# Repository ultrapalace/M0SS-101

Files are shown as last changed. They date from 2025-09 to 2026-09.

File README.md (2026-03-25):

# M0SS-101

Join our Discord server: [https://discord.gg/w7DQAhY46v](https://discord.gg/w7DQAhY46v)  

For the build guide, see [build-guide.md](build-guide.md)  
For the user manual, see [manual.md](manual.md)  
For the guide to update your firmware, see [firmware-update-guide.md](firmware-update-guide.md)

Here is a printable version of the booklet: [booklet-v1.pdf](booklet-v1.pdf)

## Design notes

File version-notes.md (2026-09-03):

**V 1.0** - October 1st, 2025
- Initial release.
---
**V 1.1** - March 25th, 2026
- Bug fix: Program Change above 17 crashed the device.
- Bug fix: USB MIDI did not respect Program Change or Channel Pressure commands.
- Bug fix: Undocumented default CC mappings existed. I removed them.
- Bug fix: Only the first MIDI USB cable was read (MIDI devices with multiple cables not respected).
- Feature: Button combo to clear all learned CC mappings (**ALT + LFO.ENV + OSC-2 WAV + click knob**).
---
**V 1.2** - April 18th, 2026
- Bug fix: Note-off should purge all matching notes in the stack.
---
**V 1.2_dualenv** - April 18th, 2026
- Feature: Dual Envelopes, press **ALT + A** to toggle between ENV I and ENV II.
    ENV I is green as usual, ENV II is lightblue.
    Anything you can do with ENV I you can also do with ENV II
- NOTE: This firmware removes ADSR curves, you are stuck with linear.
---
**V 1.3** - Aug 21st, 2026
- Feature: MIDI Channel is global. It now auto-saves, and persists resets.
- Feature: ENV and LFO are additive on the VCA. This also means that 
---
**V 1.3_dualenv** - Aug 21st, 2026
- Feature: MIDI Channel is global. It now auto-saves, and persists resets.
- Feature: ENV and LFO are additive on the VCA. This also means that 
- NOTE: This firmware removes ADSR curves, you are stuck with linear.
- NOTE: ENV-II is in ENV-INVERSION mode in your patch, this will now pin the VCA open! This is a consequence of the additive behaviour. You may need to update your patches to turn ENV-INVERSION mode off for ENV-II.
---
**V 1.4** - Sept 3rd, 2026
- Feature: Parse complex USB descriptors like Minichord.
- Bug Fix: Presets from Dual-Env firmware should survive migrating device to/from normal firmware.
---
**V 1.4_dualenv** - Sept 3rd, 2026
- Feature: Parse complex USB descriptors like Minichord.
- Bug Fix: Presets from Dual-Env firmware should survive migrating device to/from normal firmware.
---

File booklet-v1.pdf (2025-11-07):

M0SS-101 is a monophonic virtual analog synth, programmed in the Faust DSP language, on the BL616 microcontroller, which includes:

2 oscillators (OSC), with stackable square and sawtooth waveforms, each with octave (OCT) and pulse width (PW) control. Oscillator 2 can be detuned (DTN).
1 filter (VCF), with high-pass, low-pass or bandpass response, resonance control, and optional key-tracking (K-T).
1 low frequency oscillator (LFO), with square (SQR), triangle (TRI), or random (RND) waveforms, and a frequency (FRQ) range of 0.01hz to 10khz.
1 amplifier (VCA).
1 envelope generator (ENV), with attack, decay, sustain and release controls (ADSR), with timings from 0.1ms to 20s, adjustable curves, and a gain inversion mode.
1 noise generator (NSE) with pink (PN) or white (WN) noise algorithms.
1 XOR module, applied to the square waves of the 2 oscillators.
1 mixer (MXR) with inputs from each oscillator, the noise generator, and the XOR module.

1 delay module, with time (D-TM), feedback (D-FB), and mix (D-MX) controls.
1 glide module with adjustable speed.
1 pitch-bend module with adjustable upward and downward range.
9 modulation paths with individual gain, connecting the LFO and ENV to the VCF cutoff, PW, OSC-1 pitch, and VCA, or to trigger the ENV from the LFO square wave. 1 flash memory unit to store up to 17 presets, and to remap MIDI channels per preset.
2 MIDI inputs (USB-A Host and 1/8" Type-A input), with OMNI / assignable channel.
1 MIDI thru 1/8" Type-A output.
1 1/4" mono audio output, line level, 100kOhm impedance.
1 9V dc power input, center negative.
1 knob to adjust parameters, which can be depressed (clicked) to trigger the ENV.

GLOSSARY
WAV | = waveform
SQR | = square waveform
SAW | = sawtooth waveform
PW | = pulse width
OCT | = octave
MXR | = mixer
NSE | = noise generator
LFO | = low frequency oscillator
WN.PN | = white noise or pink noise
TRI | = triangle waveform
RND | = random waveform
FRQ | = frequency
LO-HI | = low or high range
CTF | = cutoff
RES | = resonance
HP | = high pass
LP | = low pass
BP | = band pass
K-T | = key tracking
A | = attack
D | = decay
S | = sustain
R | = release
D-TM | = delay time
D-FB | = delay feedback
D-MX | = delay mix

M0SS-101 USER MANUAL - V.1 - ULTRAPALACE 2025

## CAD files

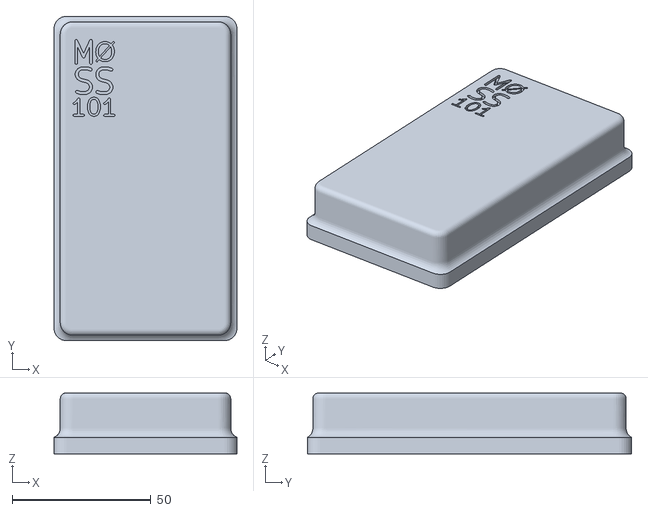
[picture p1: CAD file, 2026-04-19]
DustCover/moss-101-case_v35.stl
66.0 x 117.0 x 22.0

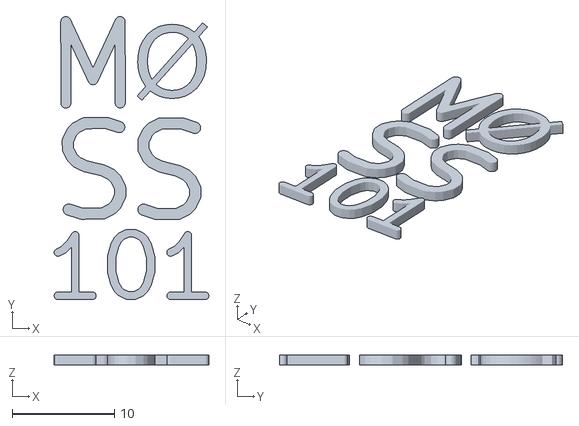
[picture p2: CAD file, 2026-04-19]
DustCover/moss-101-text_v35.stl
15.2 x 27.7 x 1.00

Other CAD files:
DustCover/moss-101_v35.step
DustCover/moss-101-no-text_v35.stl
DustCover/moss-101_v35.3mf

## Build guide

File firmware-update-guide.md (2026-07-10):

# M0SS-101 Firmware Update Guide

> NOTE: Updating the Firmware will usually result in the loss of your Presets

## STEP 1: Download the firmware image to your computer.
- The firmware Images are located in the `firmware` directory of this repository.
- You can read the [version notes](https://github.com/ultrapalace/M0SS-101/blob/main/version-notes.md) to pick the one you want to use.
- Download it to a good spot on your computer.
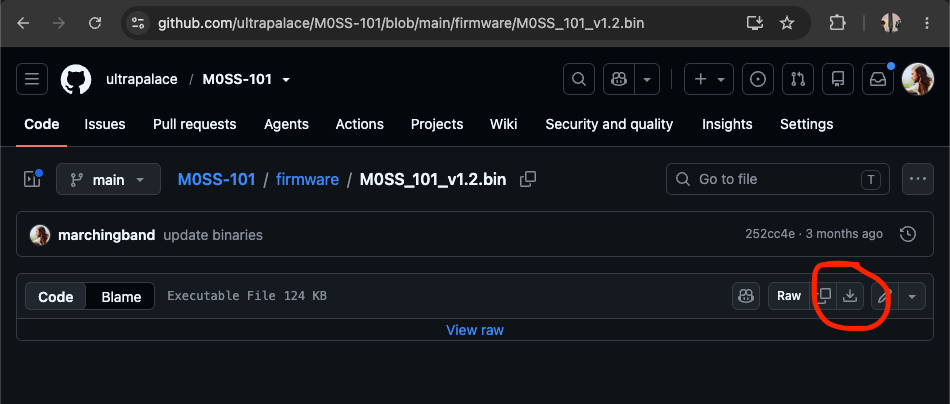
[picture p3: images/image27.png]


## STEP 2: Connect the M0SS-101
- Remove all the jacks from the M0SS-101
- Remove the 4 screws
- Remove the nut on the 1/4" Audio Jack
- Gently remove the guts of the M0SS-101
- Look for a small USB-B jack near the USB-A Host jack
- Using a USB-B cable, connect your computer to this small USB-B jack.
- Connect your 9v PSU to provide power to the M0SS-101
- It should look like this:
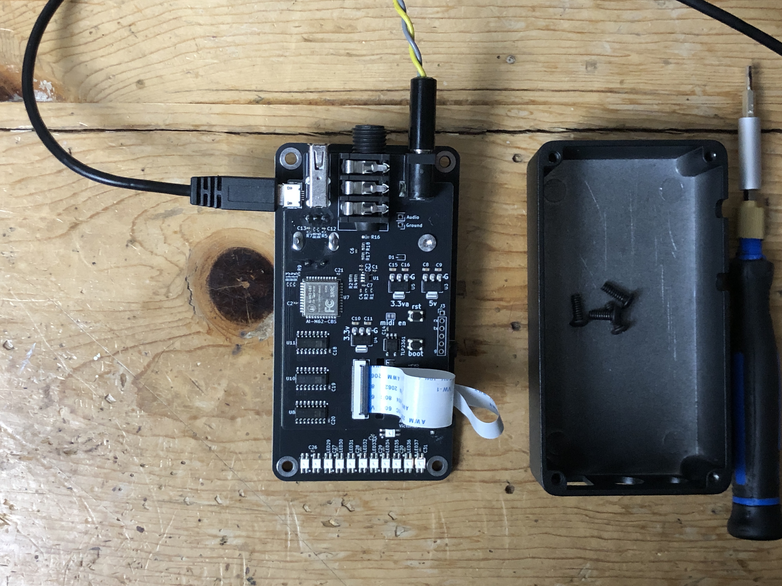
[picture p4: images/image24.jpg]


## STEP 3: Place M0SS-101 in bootloader mode
- Above the FFC cables, you will see 2 buttons labeled `BOOT` and `RST`.
- Hold the `BOOT` button down, and then click (press and release) the `RST` button. Finally release the `BOOT` button.

## STEP 4: Setup the M0SS Web Flasher utility
- Using Google Chrome (or another browser that supports WebUSB), open [https://philmillman.github.io/M0SSFlash/](https://philmillman.github.io/M0SSFlash/)
- click `Drop a .bin file here or click to browse` and select the image file you downloaded to your computer
- click `Connect Serial`, and select `Bouffalo CDC Demo` (this is the M0SS-101)

## STEP 5: Flash the firmware image
- click `Flash Firmware`
- watch the logs appear, the last log should say `Flash complete`
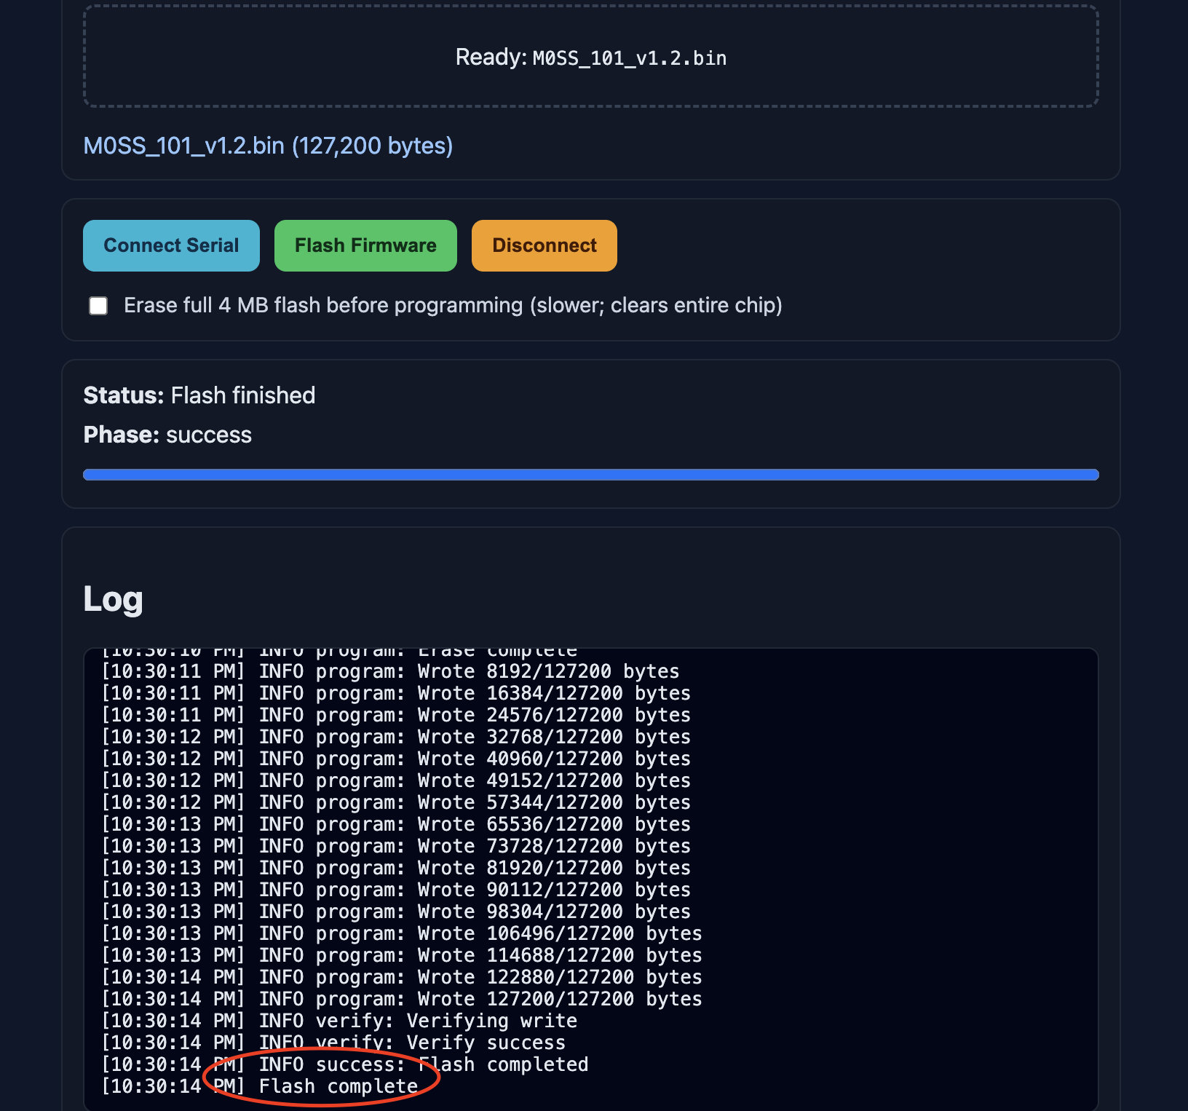
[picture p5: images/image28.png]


## STEP 6: Reset the M0SS-101
- disconnect power
- disconnect USB
- reassemble M0SS-101

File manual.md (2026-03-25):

# M0SS-101 Manual

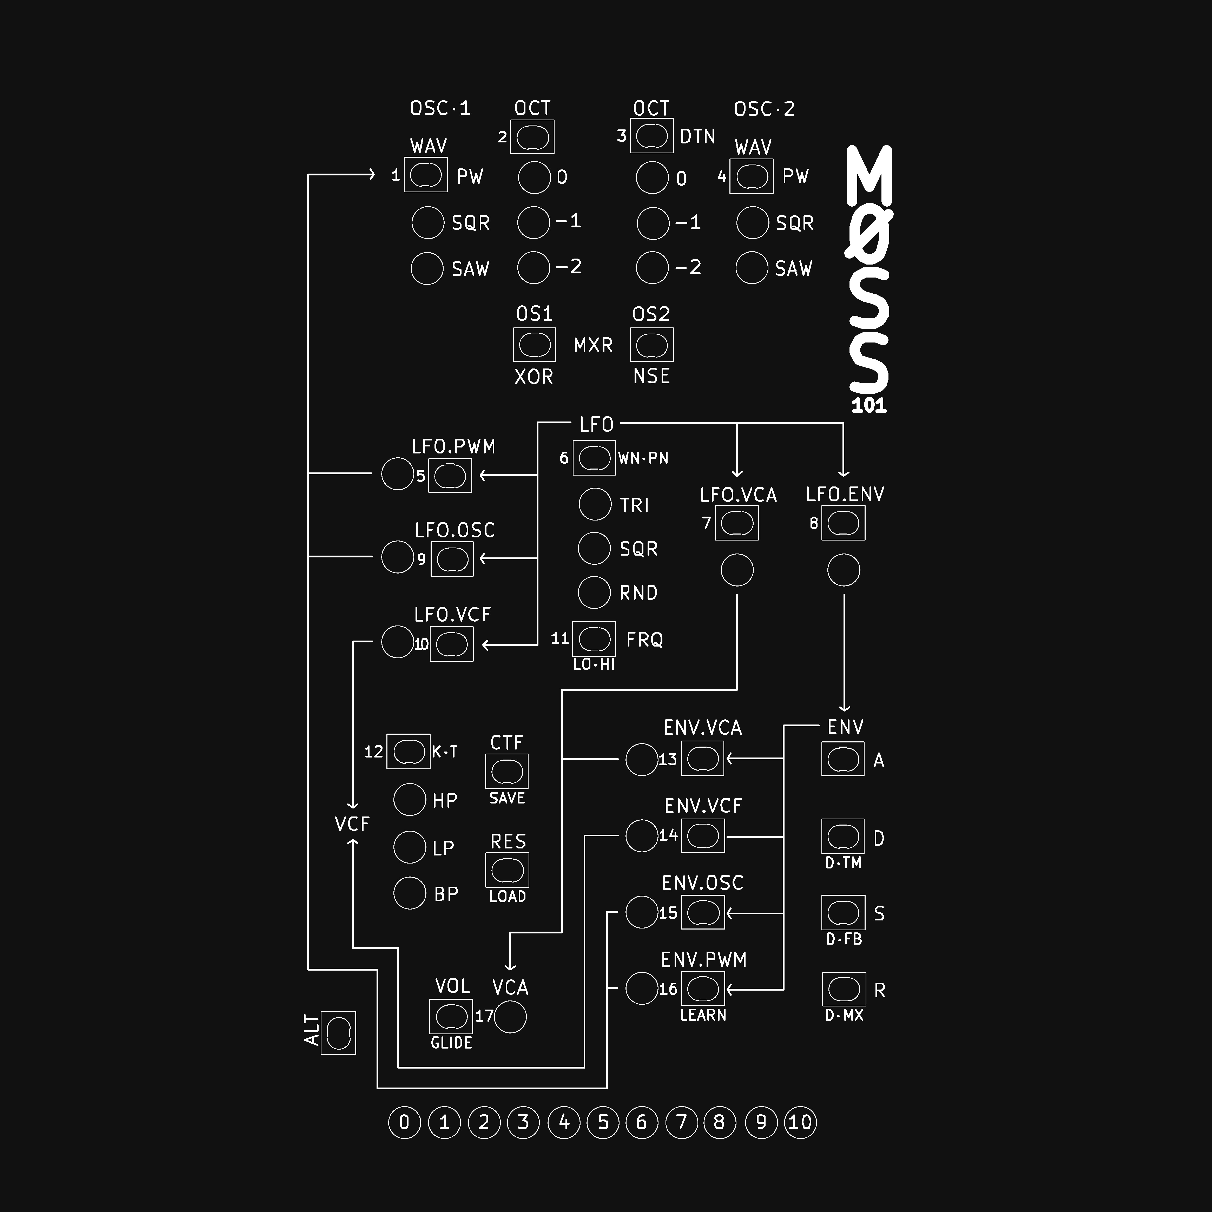
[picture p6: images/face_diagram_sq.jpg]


M0SS-101 is a monophonic virtual analog synth, programmed in the Faust DSP language, on the BL616 microcontroller, which includes:

- 2 oscillators (OSC), with stackable square and sawtooth waveforms, each with octave (OCT) and pulse width (PW) control. Oscillator 2 can be detuned (DTN).
- 1 filter (VCF), with high-pass, low-pass or bandpass response, resonance control, and optional key-tracking (K-T).
- 1 low frequency oscillator (LFO), with square (SQR), triangle (TRI), or random (RND) waveforms, and a frequency (FRQ) range of 0.01hz to 10khz.
- 1 amplifier (VCA).
- 1 envelope generator (ENV), with attack, decay, sustain and release controls (ADSR), with timings from 0.1ms to 20s, adjustable curves, and a gain inversion mode.
- 1 noise generator (NSE) with pink (PN) or white (WN) noise algorithms.
- 1 XOR module, applied to the square waves of the 2 oscillators.
- 1 mixer (MXR) with inputs from each oscillator, the noise generator, and the XOR module.
- 1 delay module, with time (D-TM), feedback (D-FB), and mix (D-MX) controls.
- 1 glide module with adjustable speed.
- 1 pitch-bend module with adjustable upward and downward range.
- 9 modulation paths with individual gain, connecting the LFO and ENV to the VCF cutoff, PW, OSC-1 pitch, and VCA, or to trigger the ENV from the LFO square wave.
- 1 flash memory unit to store up to 17 presets, and to remap MIDI channels per preset.
- 2 MIDI inputs (USB-A Host and 1/8" Type-A input), with OMNI / assignable channel.
- 1 MIDI thru 1/8" Type-A output.
- 1 1/4" mono audio output, line level, 100kOhm impedance.
- 1 9V dc power input, center negative.
- 1 knob to adjust parameters, which can be depressed (clicked) to trigger the ENV.

The primary function of each control is stamped above the control.  
The secondary function is stamped to the right, or beneath the control, hold ATL to access the secondary function.

If you activate a control, the row of bulbs near the bottom will often display its value in one of two ways:

**FADER:** this shows a value from 0 to 100, each bulb represents 10, and its faded value represents the 1's.  
**SWITCH:** the left 5 bulbs glow for on, the right 5 for off.

Most toggling and switching controls have a corresponding bulb which will glow yellow to indicate its state.  
For most signals, a corresponding bulb will glow green, pulsing with its signal level.

When the LFO is set to its high range (LO-HI), this signal will instead show as red~yellow, and the color temperature indicates its frequency.

Sometimes a control will have a specific numeric value (ex. MIDI channel).  
In this case a bulb will light near a control which has a small number stamped to its left.  
There are bulbs and controls for numbers 1 ~ 17.

---

## ENV GAIN INVERSION

When this control is active (it is active by default) attenuating the ENV.VCA signal will result in a higher initial gain for this signal.  
When this control is deactivated, the ENV.VCA signal operates more intuitively, where attenuating the signal results in a lower maximum gain.

---

## SAVE

1. Activate save mode (ATL + CTF) - free slots glow green, occupied slots glow orange.  
2. Press any slot to save (this can overwrite a slot).

---

## LOAD

1. Activate load mode (ALT + RES) - current slot glows green, loadable slots glow yellow.  
2. Press any loadable slot to load it (you will lose your current settings, if not saved)

**NOTE**  
Preset 17 comes pre-saved with some default settings. This is the preset that will always load at startup. You can customize your defaults by saving to this slot.

---

## Unmarked Controls

- **Hold (ALT + LFO.VCF)** = pitch-bend down semitones (1 ~ 12)
- **Hold (ALT + LFO.OSC)** = pitch-bend up semitones (1 ~ 12)
- **Hold (ALT + LFO.PWM)** = MIDI channel (1 ~ 17, 17 = OMNI)
- **Hold (ALT + A)** = ENV curves (1 ~ 9) (1 = very logarithmic, 5 = linear, 9 = very exponential)
- **Hold ALT + click knob + turn knob** = transpose pitch (semitones)
- **Hold ALT + turn knob** = fine-tune pitch (cents)
- **ALT + ENV.VCA** = ENV inversion mode (de)activate
- **ALT + LFO.ENV + click knob** = Panic/Reset
- **ALT + LFO.ENV + OSC-1 WAV + OSC-2 WAV + click knob** = Full Factory Reset
- **ALT + LFO.ENV + OSC-2 WAV + click knob** = Remove learned CCs for preset (added in v1.1)

---

## MIDI LEARN

1. Activate MIDI learn mode (ALT + ENV.PWM) - bulbs all glow orange.  
2. Select any control parameter - bulbs all glow yellow.  
3. Send any MIDI CC - bulbs all glow green (optionally repeat steps 2 and 3).  
4. Press ALT to exit.

This CC is now mapped to this control parameter. Save the preset to conserve this mapping.

To map aftertouch, hold a note on the keyboard, perform steps 1 and 2, then modulate the aftertouch.  
To map velocity, perform steps 1 and 2, and then press a key on the keyboard.

**NOTE**  
MIDI mappings are saved per preset.

---

## GLOSSARY

| Term | Meaning |
|---|---|
| WAV | waveform |
| SQR | square waveform |
| SAW | sawtooth waveform |
| PW | pulse width |
| OCT | octave |
| MXR | mixer |
| NSE | noise generator |
| LFO | low frequency oscillator |
| WN.PN | white noise or pink noise |
| TRI | triangle waveform |
| RND | random waveform |
| FRQ | frequency |
| LO-HI | low or high range |
| CTF | cutoff |
| RES | resonance |
| HP | high pass |
| LP | low pass |
| BP | band pass |
| K-T | key tracking |
| A | attack |
| D | decay |
| S | sustain |
| R | release |
| D-TM | delay time |
| D-FB | delay feedback |
| D-MX | delay mix |

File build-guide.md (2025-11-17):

# M0SS-101 BUILD GUIDE
( last updated November 17, 2025 )

## Here are the contents of the kit

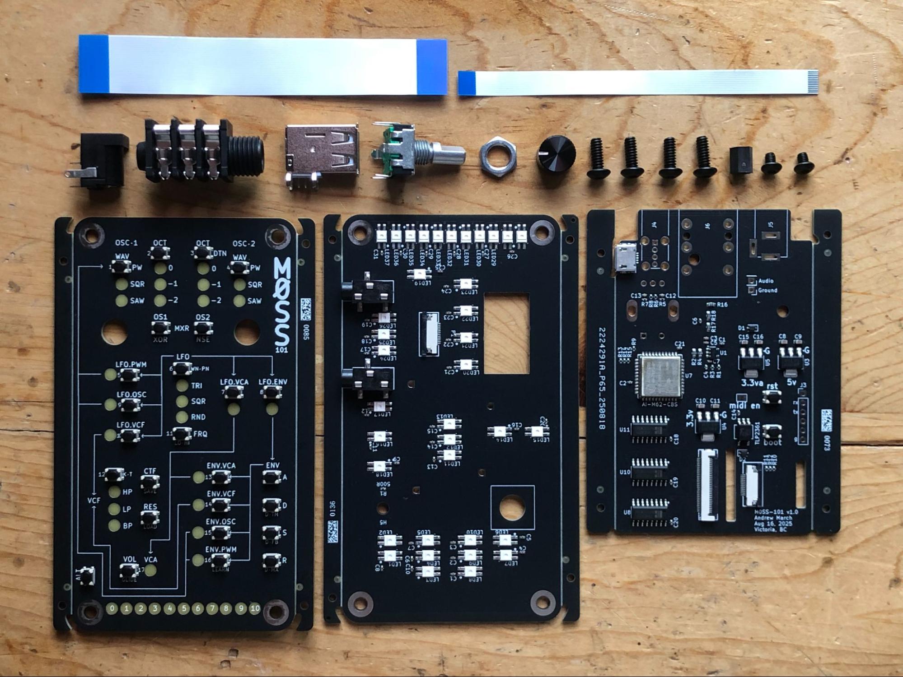
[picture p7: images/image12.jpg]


| Quantity | Item |
|---|---|
| 3 | PCBs (front panel, LED board, main board) |
| 1 | 30p Flat Flex cable |
| 1 | 12p Flat Flex cable |
| 1 | Encoder + nut |
| 1 | Encoder Knob |
| 1 | DC jack |
| 1 | 1/4" Audio jack + washer + nut |
| 1 | USB A jack |
| 1 | 7mm Standoff |
| 2 | M2 x 4mm screw, T8 |
| 5 | 6-32 x 3/8" screw, Hex |
| 4 | Silicon Feet (not pictured) |
| 1 | Aluminum enclosure (not pictured) |

<br/>

## You will need
- Pliers
- Soldering Iron
- Solder
- A T8 torx bit and driver
- A 2mm Allen Wrench or 2mm hex bit and driver
- Super Glue (optional)

<br/>

## STEP 1: Add solder to the 1/8" jacks
- These parts were sometimes not soldered well at the manufacturer. Add solder to the 6 tabs (3 tabs on each 1/8" jack) to reinforce them. During this process be VERY cautious to not melt the plastic parts of the jack, nor any of the surrounding parts, like LEDs. You can optionally add one drop of super glue to add strength, place it at the base of the part near the outside edge of the board, but be very careful not to add more then 1 drop, or you risk glueing the part shut!

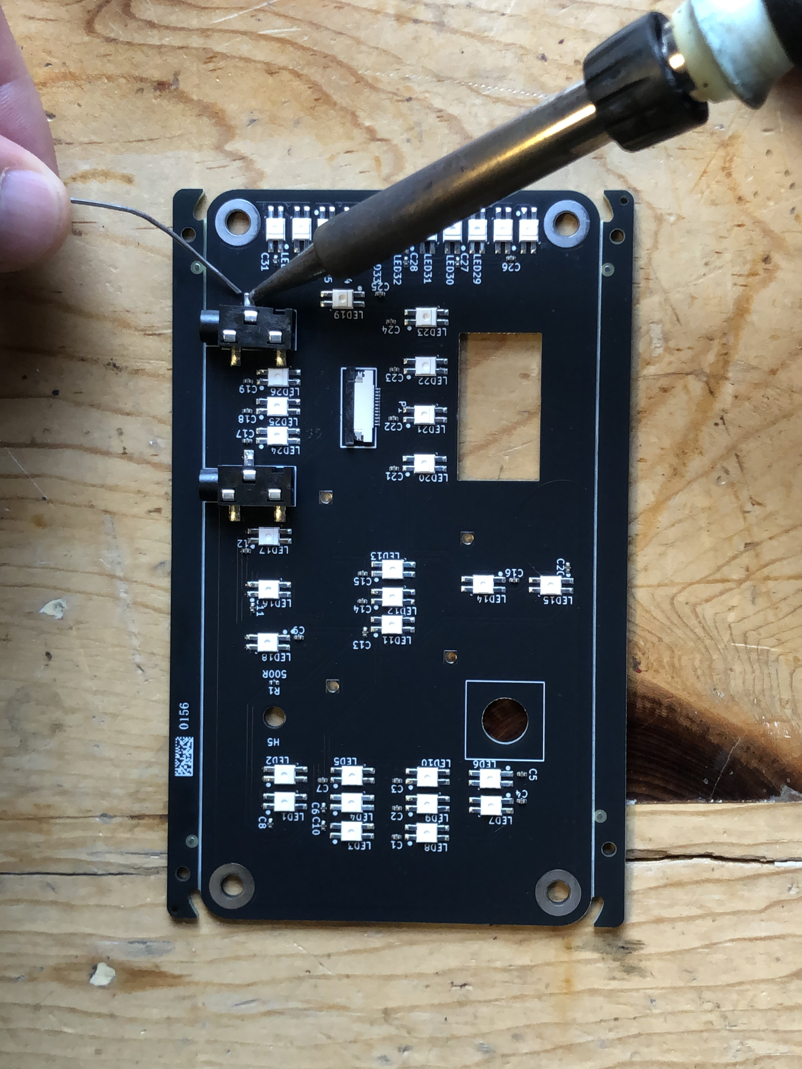
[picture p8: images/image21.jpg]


<br/>

## STEP 2: Remove the edge rails from all PCBs

- Using pliers, carefully snap off the edge rails. There are rails on the left and right sides of each PCB, 6 edges in total to be removed.

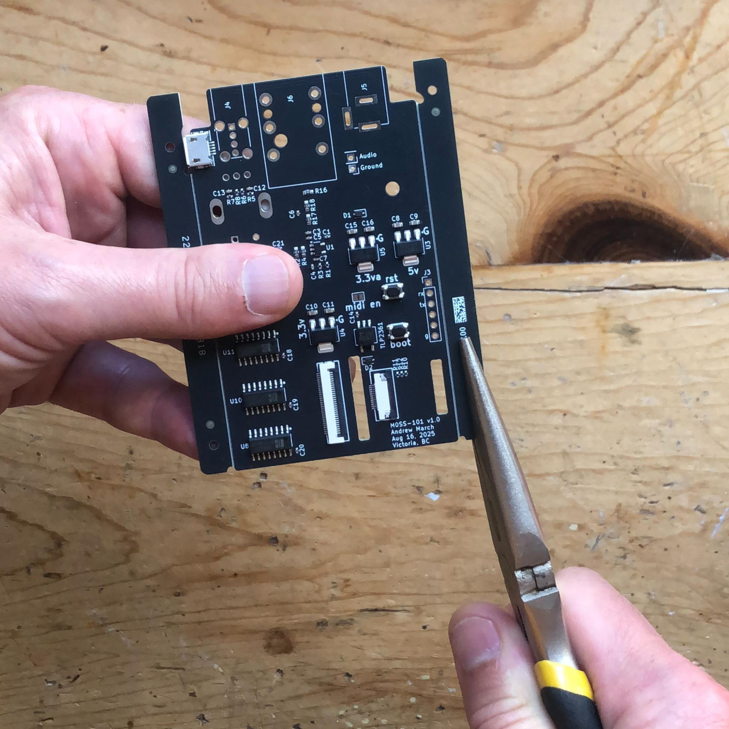
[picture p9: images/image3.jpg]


<br/>

## STEP 3: Place and solder the encoder

- Confirm you are placing the encoder on the correct side, by checking for the white outlined shape of the part, drawn on the PCB. The encoder goes on the back side.  
- Slightly bend the lugs of the encoder inward, using pliers, or by gently pressing them into the table.  
- Carefully place the encoder. If the lugs will not go in, bend them inward a little more.  
- Solder one pin of the encoder, and check that it is seated correctly.  
- Proceed to solder all the pins, and then the lugs.

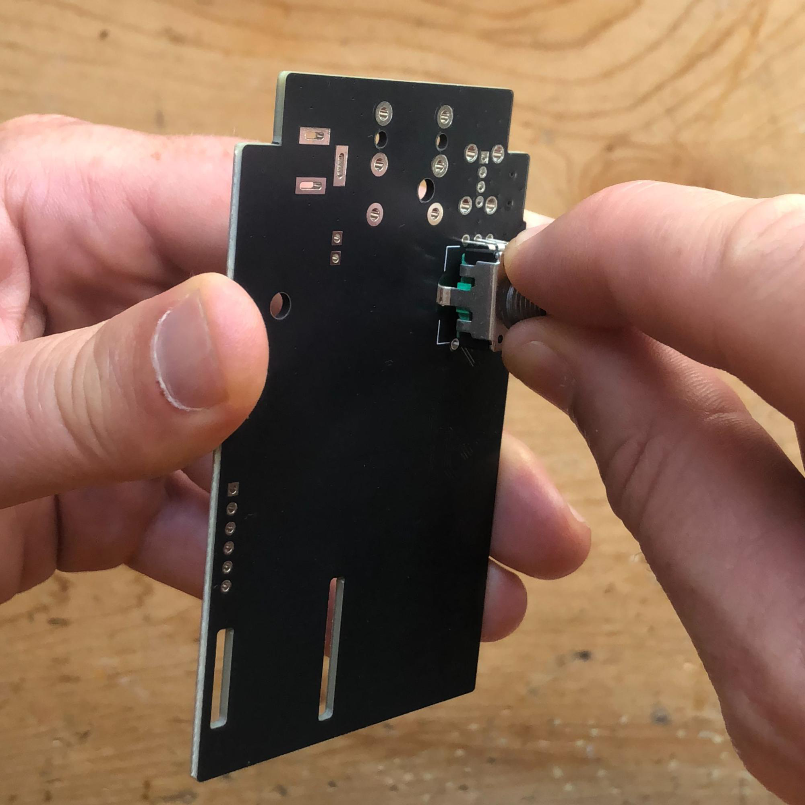
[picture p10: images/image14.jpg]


<br/>

## STEP 4: Place and solder the DC jack, audio jack and USB jack

- These parts are placed on the top side of the main PCB, look for the footprint outlines to confirm, these are installed on the opposite side as the encoder.  
- Start with the DC jack, and solder one pin, then adjust the position of the jack to be as square and straight as possible, using the white footprint outline, before soldering the remaining 2 pins.  
- Now place, and then solder, the USB jack and the audio jack.

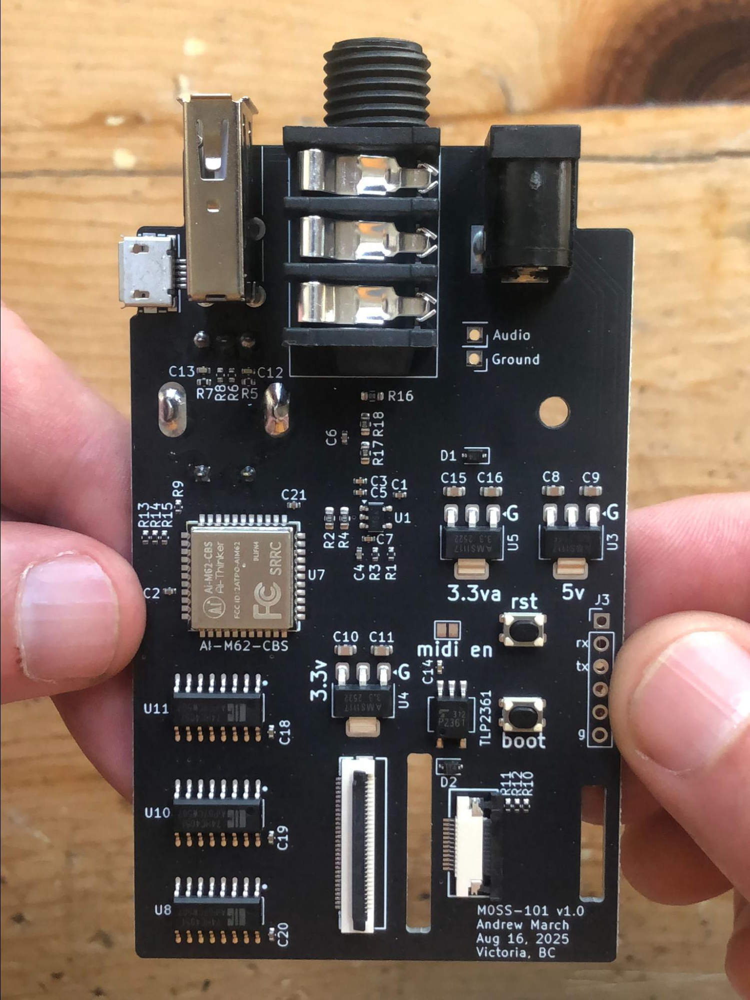
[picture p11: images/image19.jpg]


<br/>

## STEP 5: Install the standoff

- The standoff goes on the same side as the encoder, the back side of the main PCB.  
- Use a M2 x 4mm screw, and be careful to not over tighten it. ⅛ of a turn past hand-tight is great.

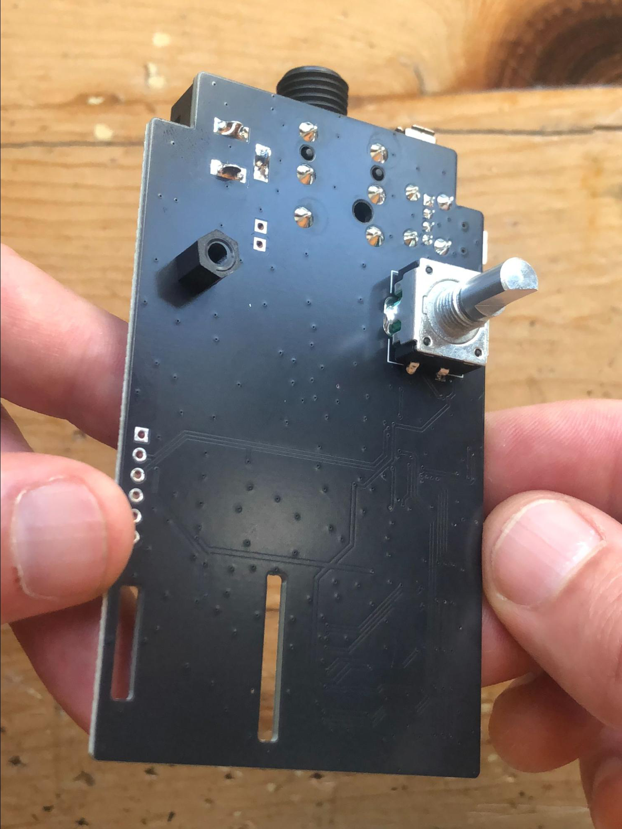
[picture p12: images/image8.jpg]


<br/>

## STEP 6: Install the Flat Flex Cables (FFCs)

- Install the large FFC onto the back side of the front panel board. The large FFC connector is a flip-lock type. Using a small tool or a fingernail, lift the black lock up and back to fully open the connector.   
- Insert the large FFC with the blue stripe up. Ensure it is fully seated and square, then close the lock.

<br/>

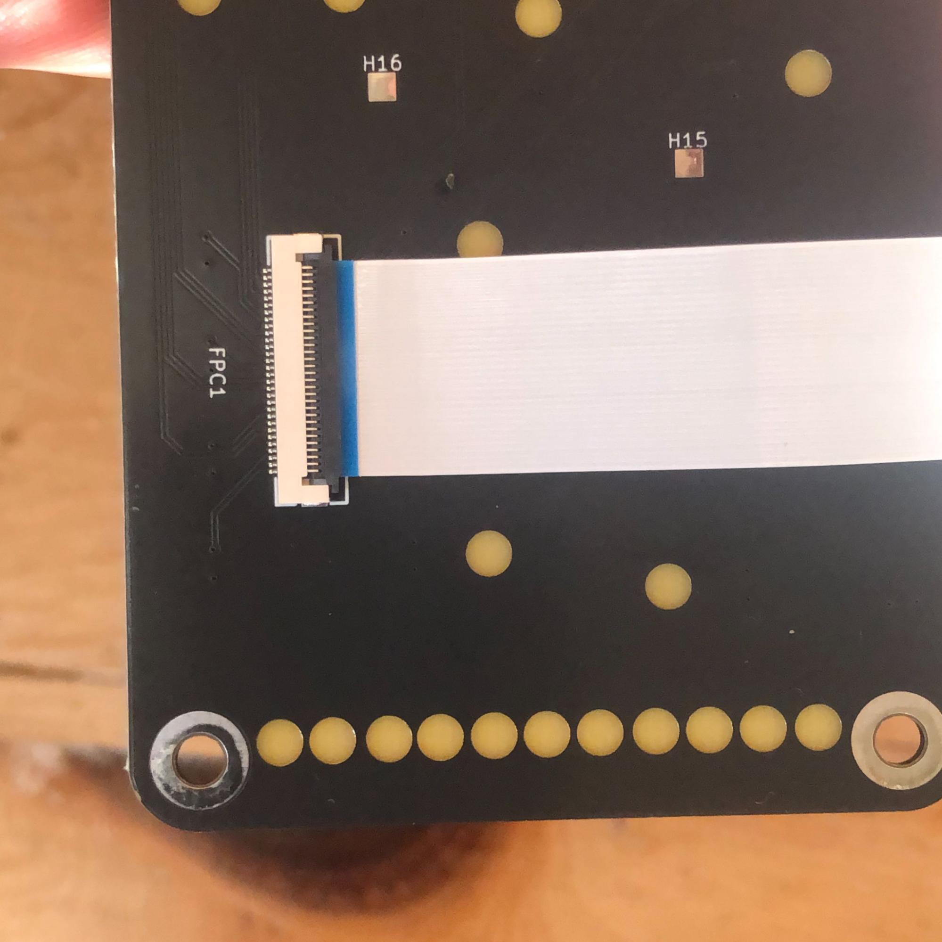
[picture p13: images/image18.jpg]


- Install the small FFC onto the LED board. The small FFC connector is a drawer-type. Using a small tool or a fingernail, gently pull laterally on the black lock to open it like a drawer.  
- Insert the small FFC with the blue stripe up, sliding it under the lock, and gently wiggle it into place. This may take some patience, and it is ok to try the other end, if you are struggling.  
- Lock the connector by pressing the drawer back into the closed position.

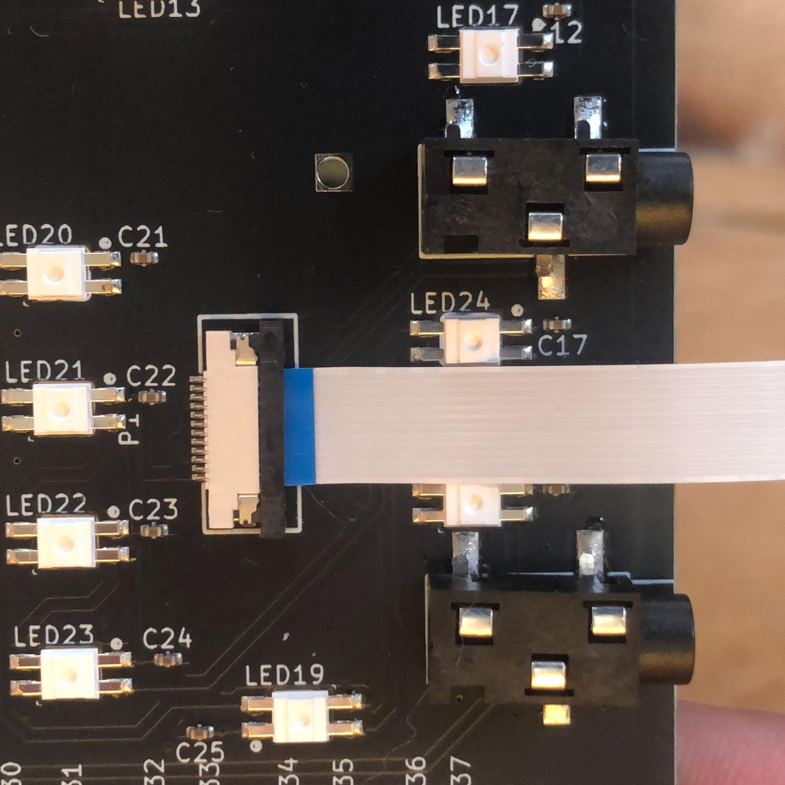
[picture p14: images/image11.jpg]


<br/>

## STEP 7: Assemble the stack-up.

- Thread the large FFC through the large cutout in the LED board, and bring the 2 boards together back-to-back.

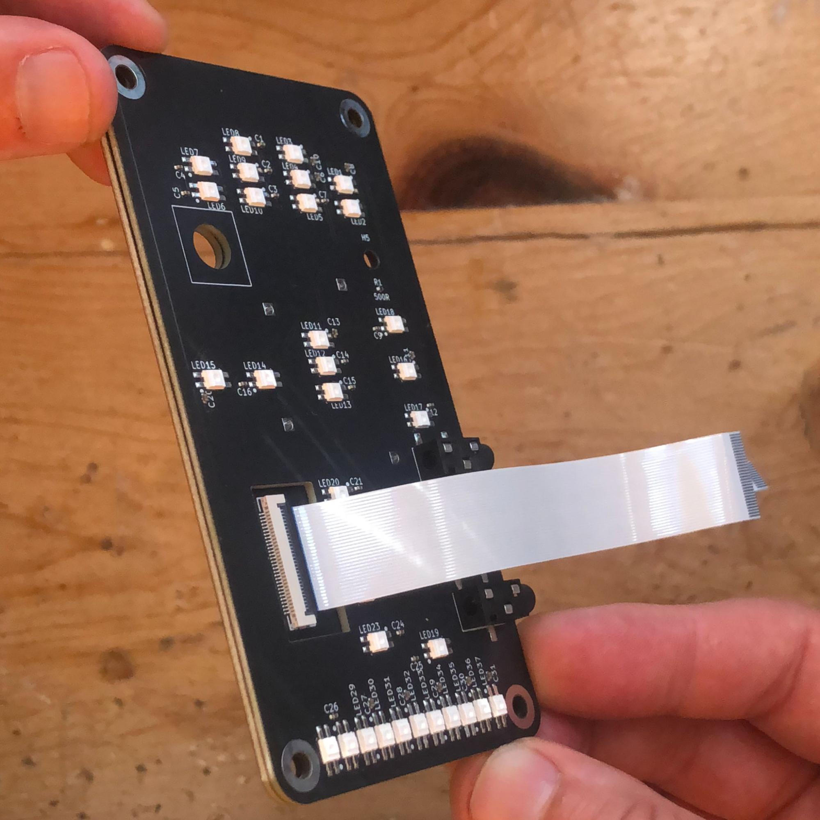
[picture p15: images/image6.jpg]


- Holding the main board with the encoder facing down toward the other boards, thread the small FFC through the smaller slit in the main board, and thread the large FFC through the wide slit in the main board. Pass the encoder through the large round hole in the 2 other boards

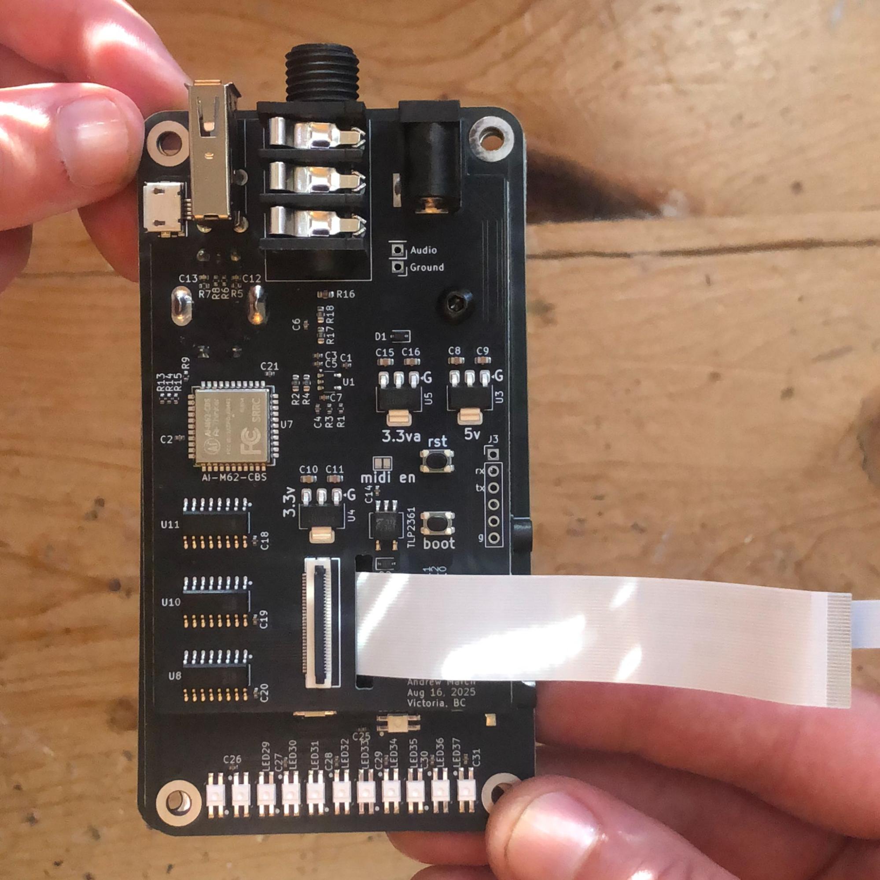
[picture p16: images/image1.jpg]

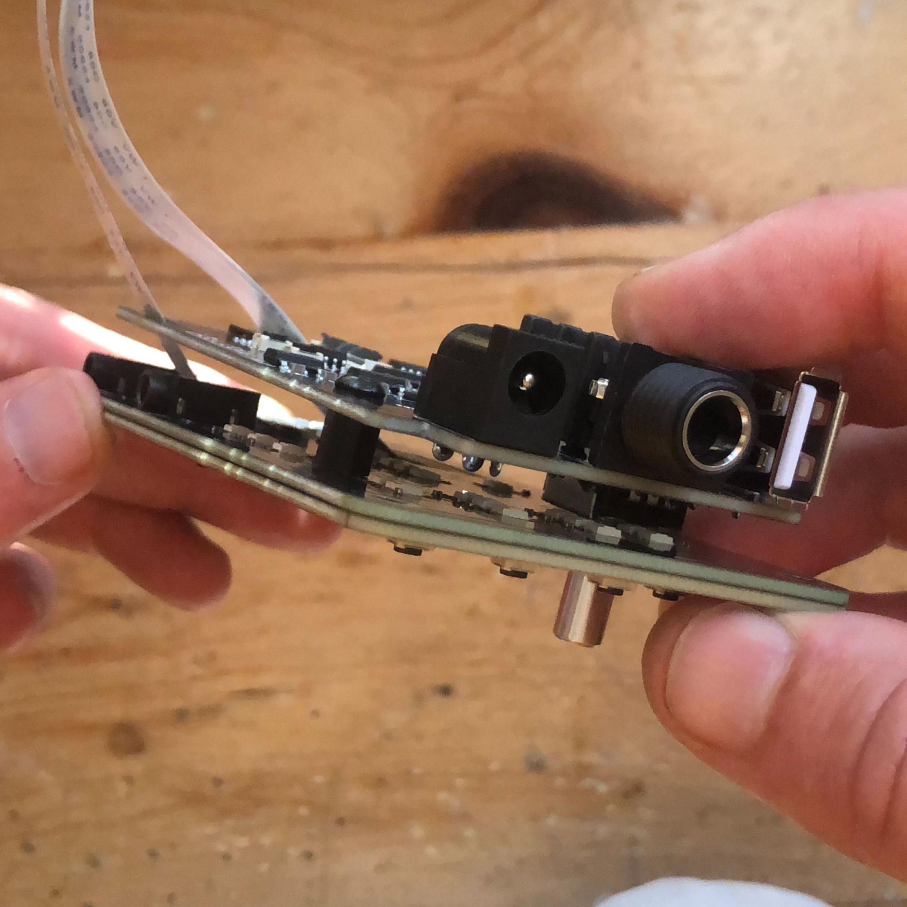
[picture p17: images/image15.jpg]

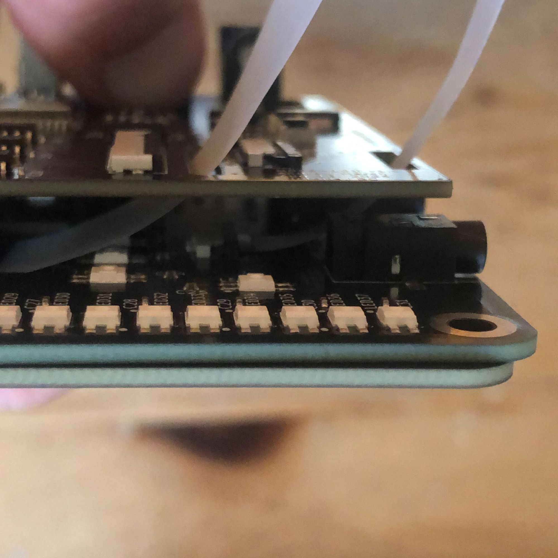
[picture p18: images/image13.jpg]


- On the front panel board, install the encoder nut, and an M2 x 4mm screw to the standoff. When tightening the encoder nut, exercise caution to not scratch the panel, and to not damage any adjacent buttons. Using a plastic socket is ideal.

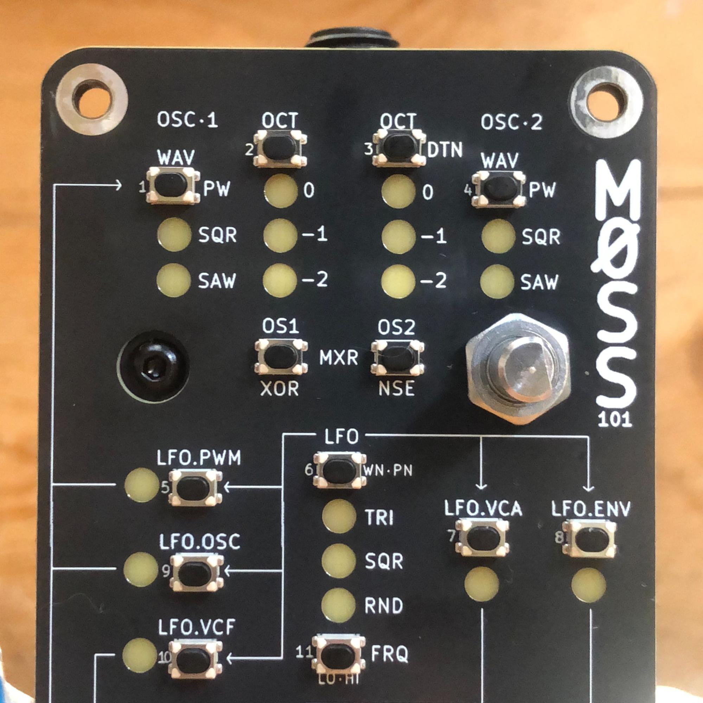
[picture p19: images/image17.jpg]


<br/>

## STEP 8: Connect the FFCs to the main board.

- Use the same procedure in step 5 to install both FFCs to their respective connectors on the main board.

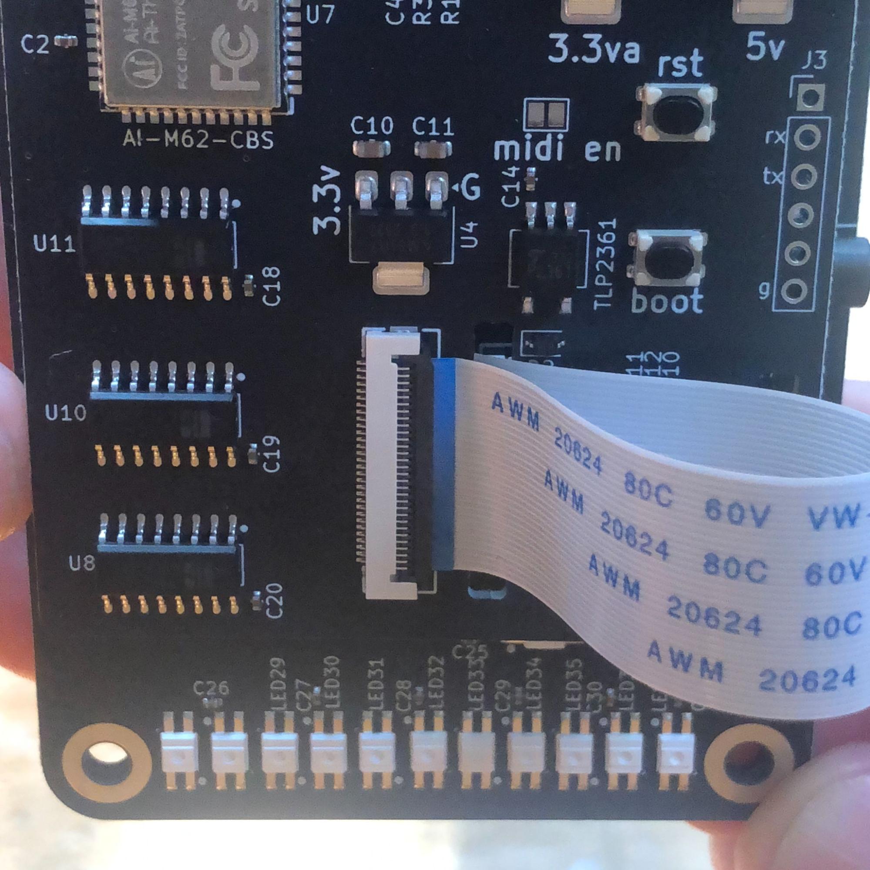
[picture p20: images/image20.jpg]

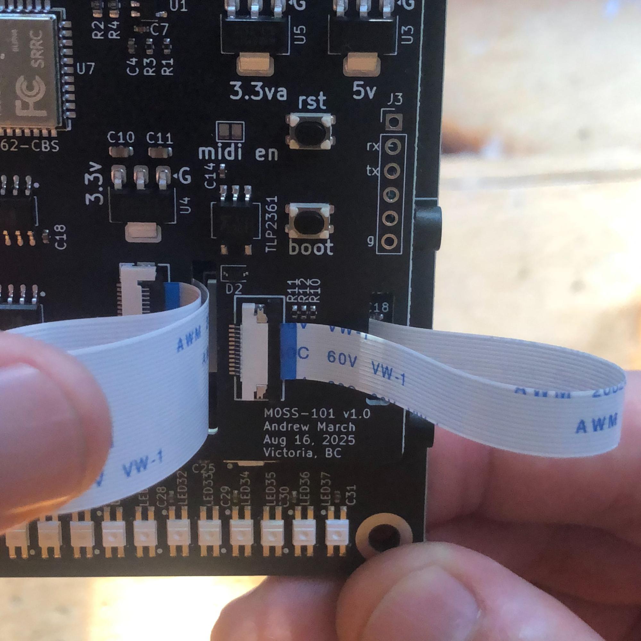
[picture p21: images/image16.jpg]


<br/>

## STEP 9: Install the enclosure

- Place the PCB assembly into the enclosure, inserting the jacks first.  
- Install the 4 large black 6-32 x 3/8" screws.  
- Install the plastic washer and nut onto the audio jack.  
- Install the knob onto the encoder, looking for the irregularity inside the knob, which mates with the flat side of the encoder shaft.  
- Optionally, affix the 4 adhesive feet, on the bottom of the enclosure, at each corner.

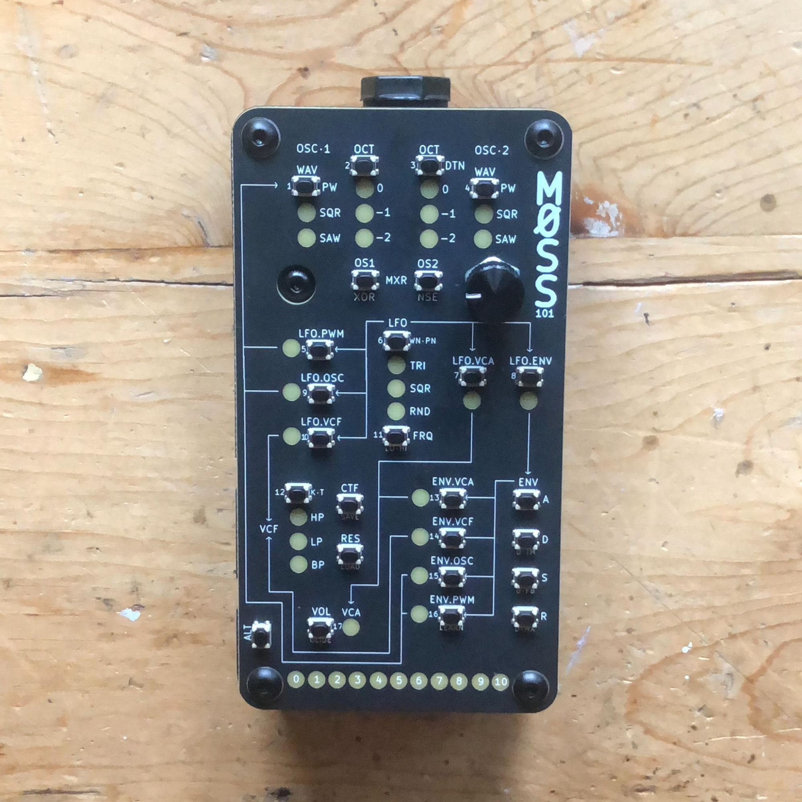
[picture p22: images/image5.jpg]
  
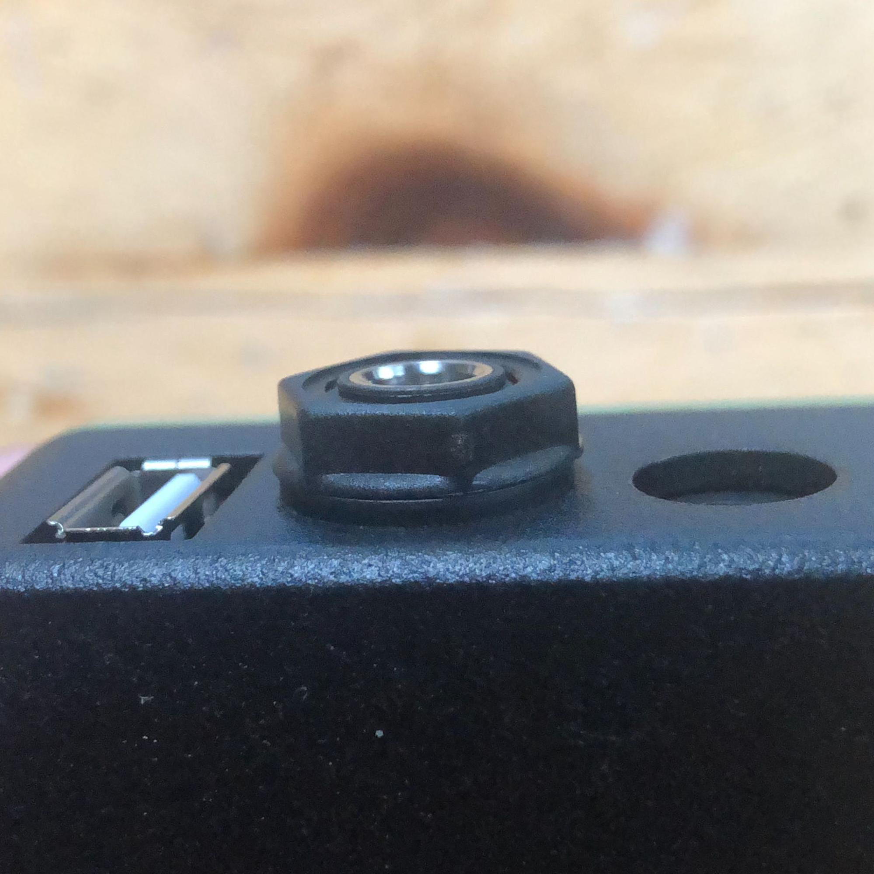
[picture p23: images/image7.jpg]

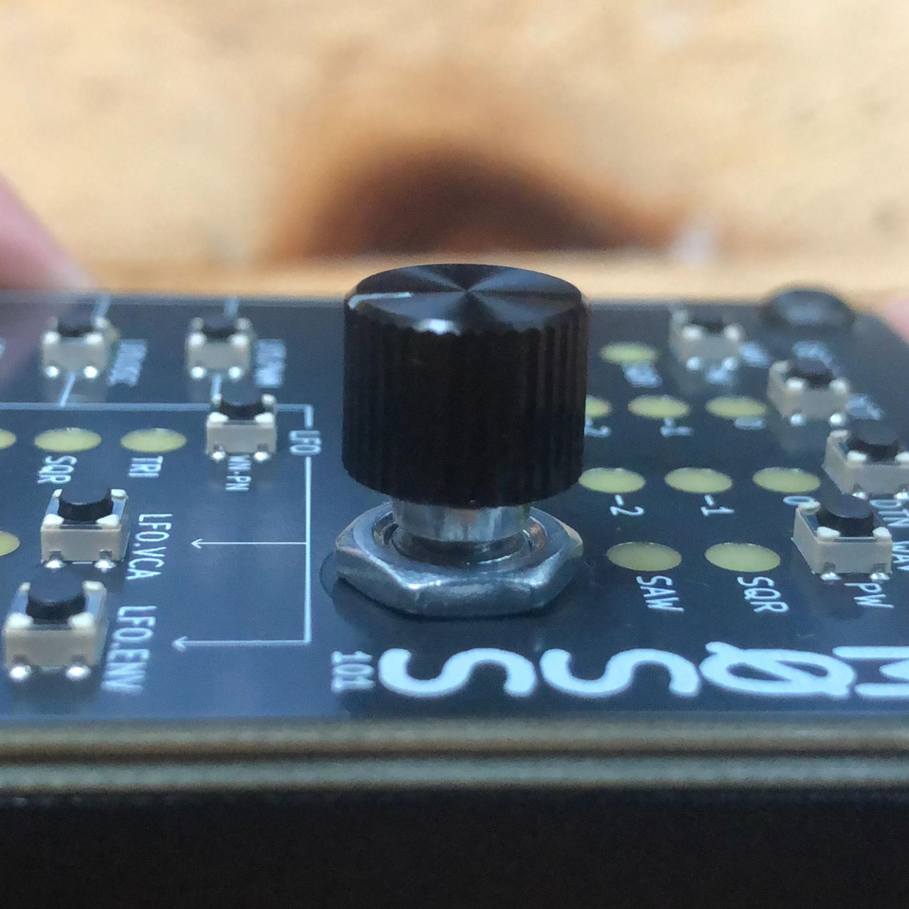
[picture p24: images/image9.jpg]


<br/>

Here some details on the I/O:
- Power input is 9v DC, center negative. M0SS-101 draws up to 800mA with a USB Device connected.
- MIDI jack 1 (closest to the top) - MIDI input, Type-A.
- MIDI jack 2 (closest to the bottom) - MIDI thru (soft-thru), Type-A.
- Audio output - 1/4" Unbalanced line level. This is actually a TRS jack but the ring is unconnected.
- USB - USB-A Host, it is safe to draw up to 500mA (USB Spec). It should work with any class compliant MIDI Device, but will not work with another USB Host (like a computer). 

<br/>

## STEP 10: First boot

- Apply power to the M0SS-101.
- Some lights should come on.
- Pressing the encoder should produce a 110hz (A2) square wave, and trigger some more lights.
- Remove power.
- Due to an initialization bug, make sure you do NOT initiate the test sequence (STEP 11) the very first time you power M0SS-101 on. Power it on at least once normally, before initiating Test Mode. This just triggers the processor to correctly initialize the presets in flash memory. If you do miss this step, and experience problems, simply initiate a factory reset to fix, instructions on how to do that are in the User Manual.

<br/>

## STEP 11 (optional): Test your M0SS-101

- While holding the “ALT” and “VOL” buttons, apply power to the M0SS-101.  
- Confirm that all the LEDs are glowing yellow.  
- Press each button, and confirm that the LEDs turn red.  
- Connect the audio jack to an amplifier or a scope, and confirm that a 110hz (A2) square wave is present.  
- Connect a MIDI device to the USB-A jack, send some MIDI, and confirm that the LEDs flash blue.  
- Connect a MIDI device to the ⅛” MIDI input jack (the one closer to the back), send some MIDI, and confirm that the LEDs flash blue.  
- Turn the encoder clockwise, and confirm that the LEDs flash green.  
- Turn the encoder counter-clockwise, and confirm that the LEDs flash blue.

<br/>

## STEP 12: Construct the manual

- I found this cute diagram online, use it to fold your manual into a tiny book.

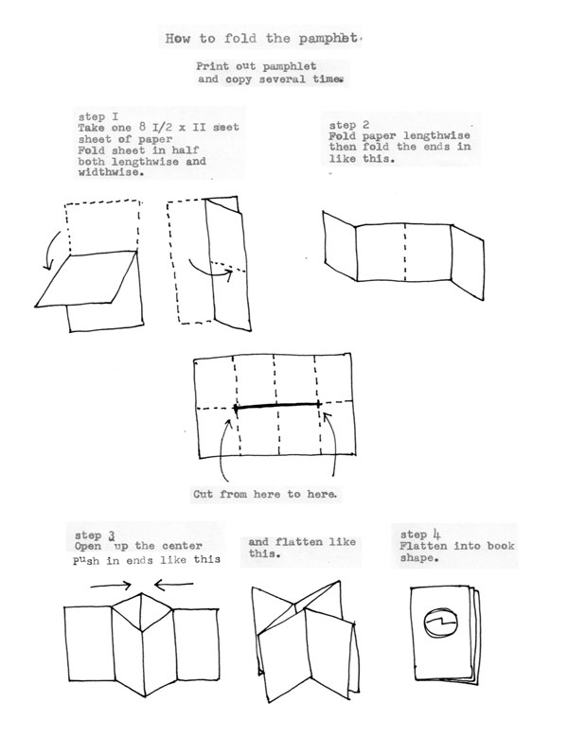
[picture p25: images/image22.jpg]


- If you have done it right, it should look like this

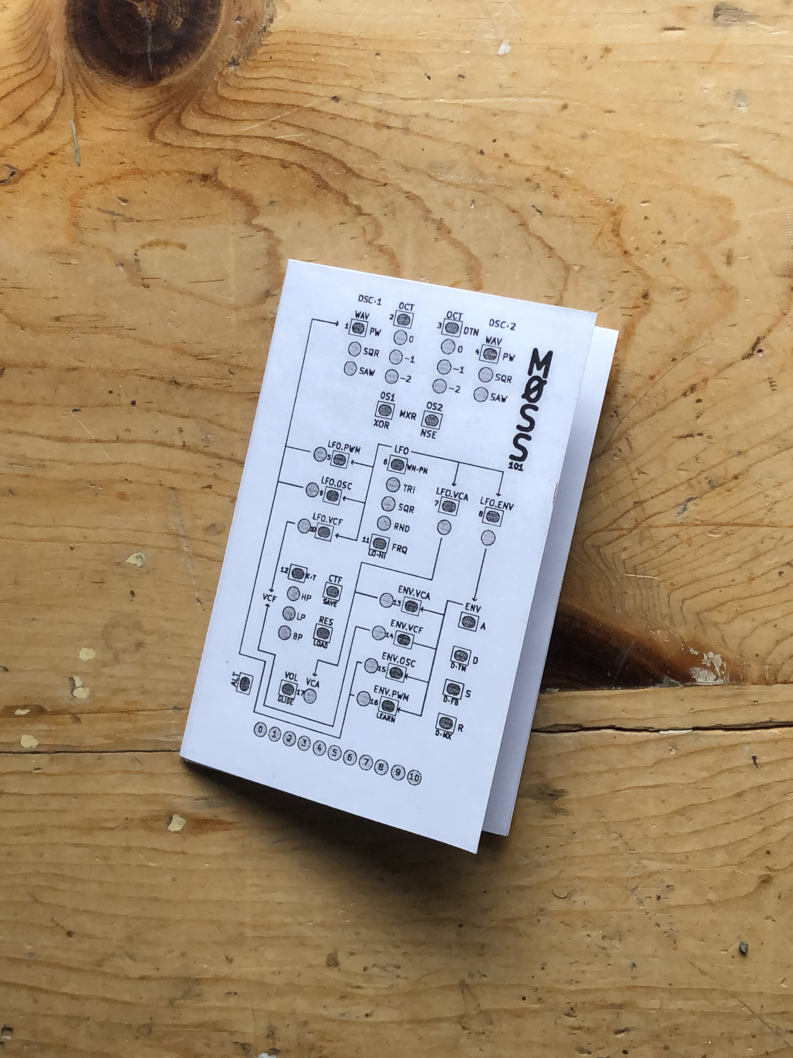
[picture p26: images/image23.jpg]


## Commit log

2025-11-07 Add link to printable version of the booklet
2026-04-19 add dust cover and new binaries
    [moss-101-case_v35.stl, moss-101-no-text_v35.stl, moss-101-text_v35.stl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]
2026-09-03 support minichord, switch to/from dual_env should not clear presets
